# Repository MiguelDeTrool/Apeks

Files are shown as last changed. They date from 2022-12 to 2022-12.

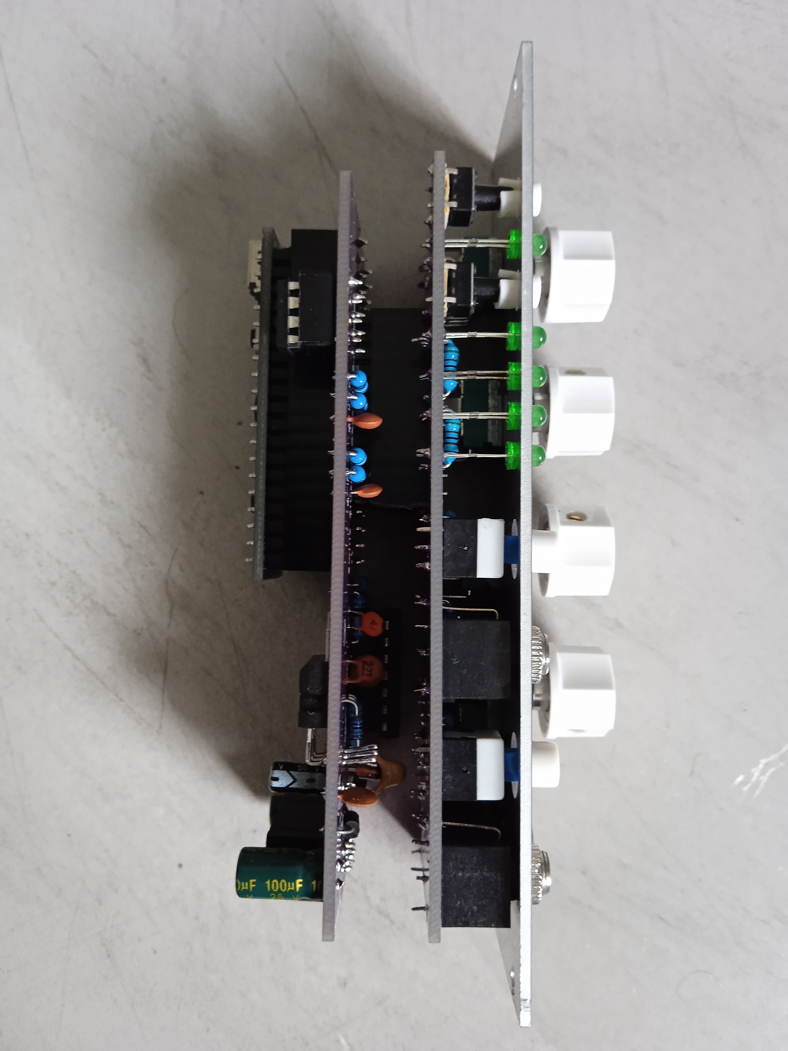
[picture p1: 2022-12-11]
img/4_left.jpg

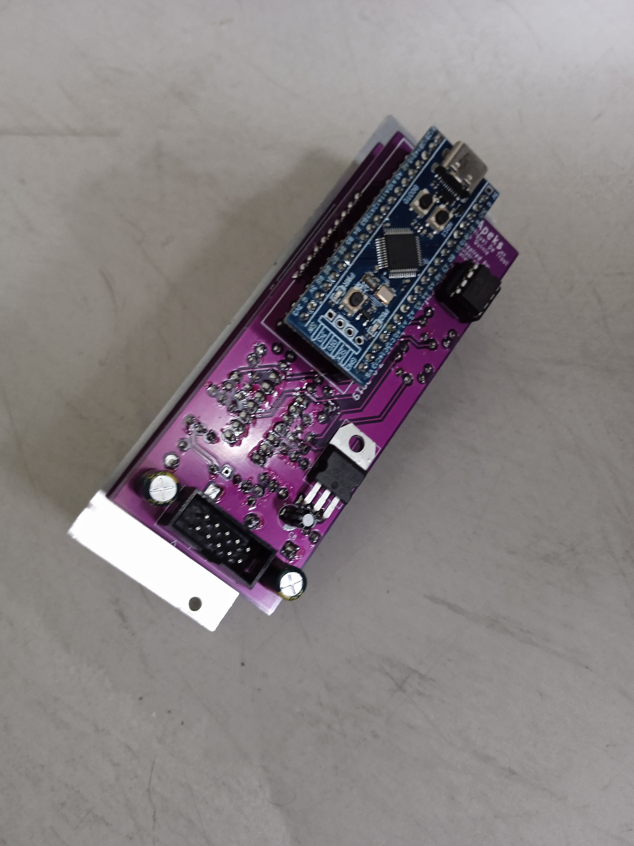
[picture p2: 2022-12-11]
img/3_back.jpg

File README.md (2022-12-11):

# Apeks

Apeks is a DIY 12-bit through-hole adaptation of Mutable Instruments Peaks. Peaks was discontinued in 2017, but it's still pretty useful, and you can still see it in modern racks. For a starter system, it offers lots of functionality, so we made a version that's cheap and easy to fabricate, build, and modify.



## Hardware:
We saw what sound-force.nl did for Braids, and noticed Peaks used the same classic STM32 processor, so the same style of conversion could be done. Overall the conversion process was very similar to what Sound Force describes in their page about Braids: the layout is the same as it leaves space for THT components, the main PCB is shorter than 100mm, and the firmware only needs to have a few files changed (dac.h, dac.cc, lfo.h, and mini_sequencer.h).

The output stage needed to be modified slightly, as Peaks' output swing is 16V, which at 12 bits means the resolution would only be at almost 4mV. That's almost 5 cents at 1V/Oct, which is too much, as we could hear the steps in the output.

This version uses a 12 bit DAC, and the output op-amps scale the output to +/- 5V. This allows for a resolution of around 2.44mV, which we find acceptable for non-pitch related modulation.

## Firmware
For the DAC, the dac.h file is modified to bitshift the 16 bit values by 4 bits. The SPI output message use masks according to the MCP4822 write commands.

To bring the LFOs and mini-sequencers up to the maximum level (if not, they would be at around +/-3.125V), a couple of changes are needed. The lfo.h set_level arguments need to be set to 65535 instead of 40960, and in the output line of mini_sequencer.h, the same number needs to be changed.

The firmware is available as source and pre-compiled. We used a CP2102 and STM32CubeProg to program the chip (see images for a wiring diagram).

When you use the module for the first time, flash the bootloader and the main firmware. Then take care to calibrate it according to [these instructions](https://forum.mutable-instruments.net/t/trimpots-versus-software-calibration-of-peaks/8213/2).

## Panel
There are two panel versions. One uses 6mm caps for the trigger buttons, with LEDs that shine through the PCB beside them. The other has 8mm holes for the original illuminated buttons.
*Note: We've only tried our prototype panels for now, we haven't had these panels fabricated yet.*

## Further modifications
This version stays as close as possible to the original, but we'd be excited to see further modifications and improvements. We're working on a 64kb firmware (no easter egg and smaller bootloader), and a Dead Man's Catch adaptation.

But why not try to add CV inputs with attenuverters for the pots, make an SMD micro version that can be pre-fabbed, use an adapter board to use another DAC, see if you can do the same for Tides v1 etc...

## Build notes
We've included a BOM with links to Tayda, where you can source almost all the parts quite cheaply. The BOM includes some helpful notes about some components.

It's very hard to get ahold of boards with genuine STM32 chips right now. We haven't tested this with any other versions, like APM32, GD32, CH32 etc... but we can only assume that they will work too. **Just be careful that the pinouts match!**

## Contact
This is a DIY project, with no instructions or build support. However, I can try to answer some questions you may have (if I have the time) at [migueldetrool@protonmail.com](mailto:migueldetrool@protonmail.com).

Check out [Quinie's blog and shop](https://www.quinie.nl), where there are PCB and panels for sale.

*If you get these boards or panels fabricated, please do contact me. These boards have been tested, but still, maybe I oversaw a problem, so it would be good to have confirmation that these work for others.*

### Thanks
Thanks to sound-force.nl and matias-levy for inspiration, and Emilie Gillet for the original design and helpful forum posts.

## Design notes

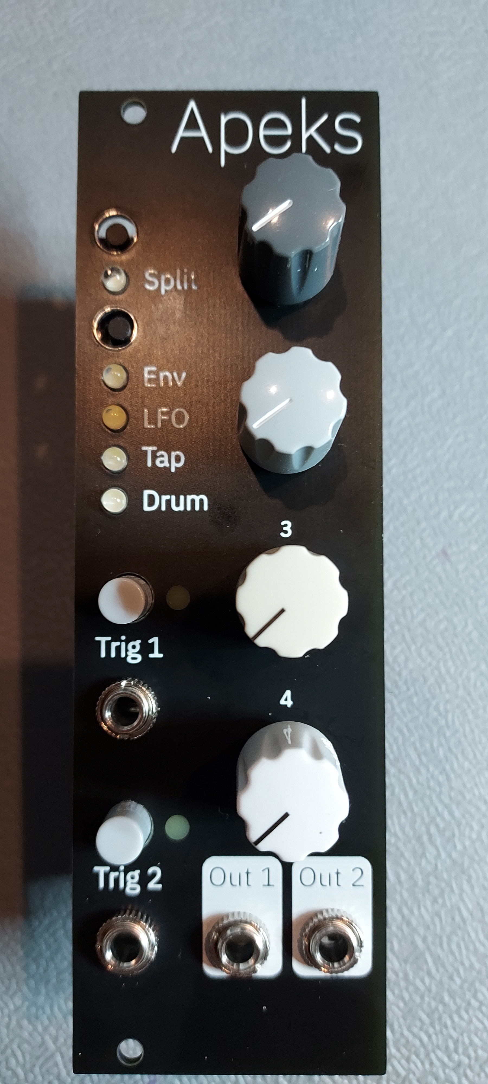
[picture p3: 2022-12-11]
img/7_front.jpg

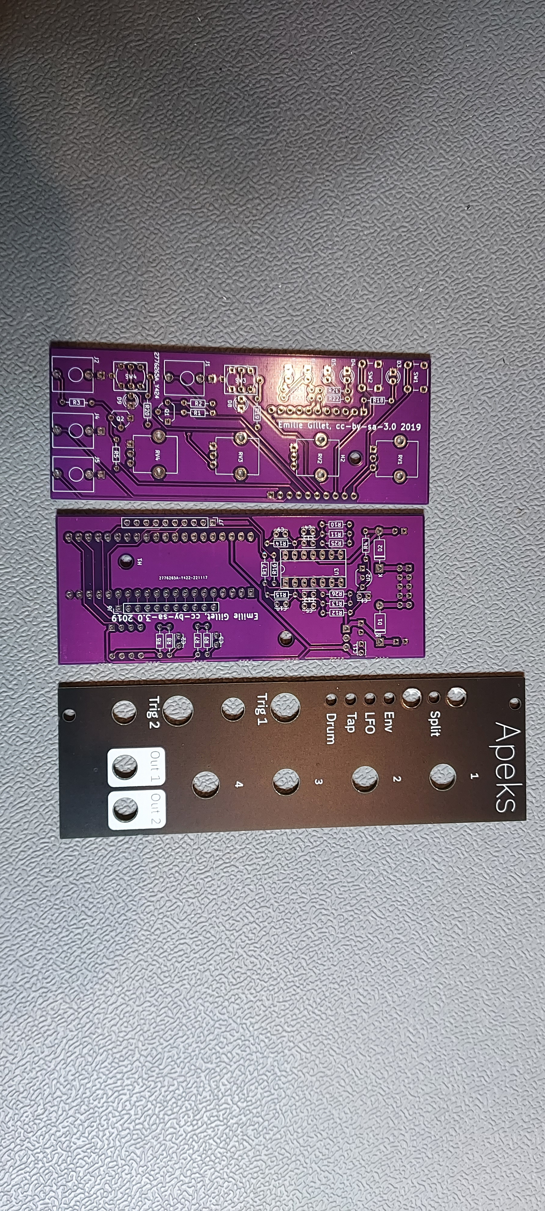
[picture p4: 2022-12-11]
img/6_three_PCBs.jpg

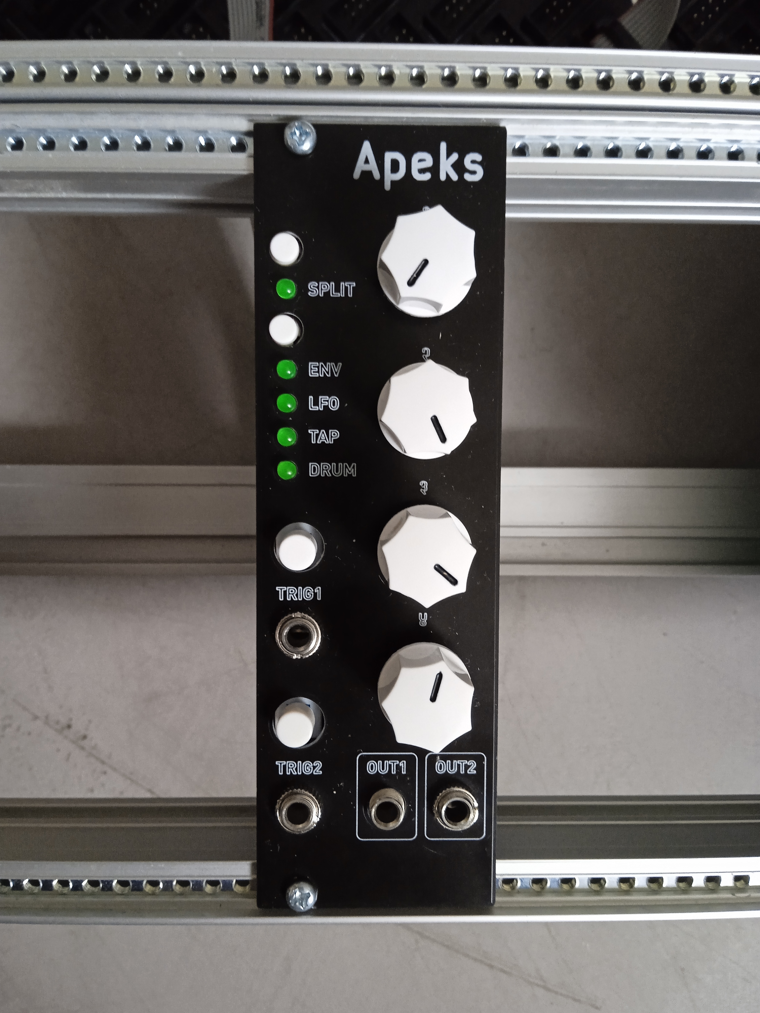
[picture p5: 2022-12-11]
img/1_front.jpg

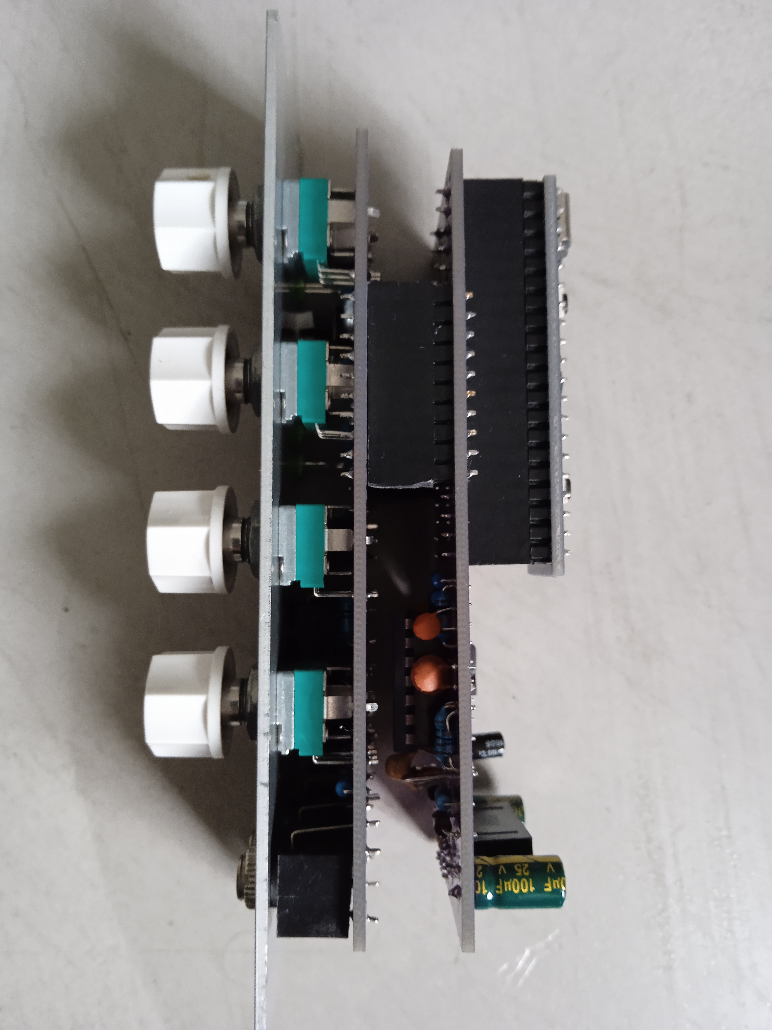
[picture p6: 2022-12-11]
img/5_right.jpg

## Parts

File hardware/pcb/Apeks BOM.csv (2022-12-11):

Designator | Description | Quantity | Designation | Link | Notes
C1 | C_Disc_D3.4mm_W2.1mm_P2.50mm | 1 | 0.47uf | https://www.taydaelectronics.com/capacitors/ceramic-disc-capacitors/test-group-2.html | Same link for all ceramic capacitors
C11,C12,C13 | C_Disc_D3.4mm_W2.1mm_P2.50mm | 3 | 100n
C4,C2,C3,C5 | C_Disc_D3.4mm_W2.1mm_P2.50mm | 4 | 220p
C6,C7 | CP_Radial_D5.0mm_P2.50mm | 2 | 22uf | https://www.taydaelectronics.com/22uf-25v-85c-radial-electrolytic-capacitor-5x11mm.html
C8 | CP_Radial_D5.0mm_P2.50mm | 1 | 0,33u | https://www.taydaelectronics.com/0-33-uf-50v-85c-radial-electrolytic-capacitor.html
C9,C10 | C_Disc_D3.4mm_W2.1mm_P2.50mm | 2 | 39p
D1,D2 | D_DO-41_SOD81_P10.16mm_Horizontal | 2 | 1N5817 | https://www.taydaelectronics.com/1n5817-diode-schottky-1a-20v.html | 1N5819 is actually cheaper
D3,D4,D5,D6,D7,D8,D9 | LED_D3.0mm | 7 | LED | https://www.taydaelectronics.com/led-3mm-green.html | Depending on what LEDs you get, they might be too bright and you’ll need bigger resistors for them
J1 | Jack_3.5mm_QingPu_WQP-PJ398SM_Vertical_CircularHoles | 1 | in1 | https://www.taydaelectronics.com/pj-3001f-3-5-mm-mono-phone-jack.html | Same link for all jacks
J2 | Jack_3.5mm_QingPu_WQP-PJ398SM_Vertical_CircularHoles | 1 | in2
J3 | IDC-Header_2x05_P2.54mm_Vertical | 1 | Eurorack Power | https://www.taydaelectronics.com/10-pin-box-header-connector-2-54mm.html
J4 | Jack_3.5mm_QingPu_WQP-PJ398SM_Vertical_CircularHoles | 1 | out1
J5 | Jack_3.5mm_QingPu_WQP-PJ398SM_Vertical_CircularHoles | 1 | out2
J6 | PinHeader_1x11_P2.54mm_Vertical | 1 | Conn_01x11 | https://www.taydaelectronics.com/40-pin-2-54-mm-single-row-pin-header-strip.html | Cut down to size
J7 | PinHeader_1x10_P2.54mm_Vertical | 1 | Conn_01x10 | https://www.taydaelectronics.com/40-pin-2-54-mm-single-row-female-pin-header.html | Cut down to size
J8 | PinSocket_1x11_P2.54mm_Vertical | 1 | Conn_01x11
J9 | PinSocket_1x10_P2.54mm_Vertical | 1 | Conn_01x10
Q1,Q2 | TO-92_Wide | 2 | 2N3904 | https://www.taydaelectronics.com/2n3904-npn-general-propose-transistor.html
R1,R3,R14,R15 | R_Axial_DIN0204_L3.6mm_D1.6mm_P7.62mm_Horizontal | 4 | 100k | https://www.taydaelectronics.com/resistors/1-4w-metal-film-resistors/test-group-2.html | Same link for all resistors
R10,R12 | R_Axial_DIN0204_L3.6mm_D1.6mm_P7.62mm_Horizontal | 2 | 200k
R11,R18,R21,R22,R23,R24,R19,R20,R13 | R_Axial_DIN0204_L3.6mm_D1.6mm_P7.62mm_Horizontal | 9 | 2k
R16,R17 | R_Axial_DIN0204_L3.6mm_D1.6mm_P7.62mm_Horizontal | 2 | 1k
R2,R5 | R_Axial_DIN0204_L3.6mm_D1.6mm_P7.62mm_Horizontal | 2 | 10k
R4 | R_Axial_DIN0204_L3.6mm_D1.6mm_P7.62mm_Horizontal | 1 | 3.3k
R6,R7,R8,R9,R25,R26 | R_Axial_DIN0204_L3.6mm_D1.6mm_P7.62mm_Horizontal | 6 | 39k
RV1,RV2,RV3,RV4 | Potentiometer_Alpha_RD901F-40-00D_Single_Vertical_CircularHoles | 4 | B10k | https://www.taydaelectronics.com/tayda-10k-ohm-linear-taper-potentiometer-round-shaft-pcb-9mm-6-35-mm.html
SW1,SW2 | SW_PUSH_6mm | 2 | SW_Push_Dual | https://www.aliexpress.com/item/32726374514.html | Ideally, you want 6*6mm tact switches with square heads, that will fit the cap nicely. If you want to only order from tayda, you can probably force the cap onto a round head switch, like this https://www.taydaelectronics.com/tact-switch-6-6mm-7-3mm-through-hole-spst-no.html
SW3 | LP4OA1PBCT | 1 | SW_TRIG1 | https://www.taydaelectronics.com/push-button-switch-momentary-dc-30v-0-1a-dpdt-7x7mm.html | For the original illuminated buttons with 8mm head, you can get these ones https://www.aliexpress.com/item/4000415375387.html?gatewayAdapt=4itemAdapt
SW4 | LP4OA1PBCT | 1 | SW_TRIG2 |  | Depending on which buttons you use, you may have to do some light re-wiring by adding jumpers between certain pins. On the board, the two middle pins need to connect to the two bottom pins when the button is pressed.
U1 | BluePill_STM32F103C | 1 | Bluepill |  | Needs STM32F103CBT6 version, with 128kb memory. You can only get clones of these currently. I’m working on a smaller version of firmware to work on 64kb.
U2 | TO-92_Inline_Wide | 1 | LM4040LP-10 |  | Not common on ali sites, since the output is not v/oct, it’s easiest to just replace it with a zener like this: https://www.taydaelectronics.com/1n4740a-1n4740-zener-diode-10v-1w.html
U3 | DIP-14_W7.62mm_Socket_LongPads | 1 | TL074 | https://www.taydaelectronics.com/tl074-quad-operational-amplifier-j-fet-pdip-14-tl074cn.html
U4 | DIP-8_W7.62mm | 1 | MCP4822 |  | Can be found on ali sites, like here: https://www.aliexpress.com/item/33020375029.html
U5 | TO-220-3_Horizontal_TabDown | 1 | LM7805 | https://www.taydaelectronics.com/lm7805-l7805-7805-voltage-regulator-ic-5v-1-5a.html
Extras
 | STM32 Blue Pill headers | 2 |  | https://www.taydaelectronics.com/20-pin-2-54-mm-single-row-female-pin-header.html | Some clone boards have a 5V pin at the top right, instead of the usual ground. Cut the pin off if it has 5V.
 | Tactile switch caps | 2 |  | https://www.taydaelectronics.com/push-button-switch-caps-black-color-5x8-85-mm.html
 | Push button caps, for 6mm version | 2 |  | https://www.taydaelectronics.com/push-button-switch-caps-black-color-6-x-5-mm.html
 | Potentiometer knobs | 4 |  | https://www.taydaelectronics.com/knob-davies-1900h-clone-black.html
 | 14 pin socket | 1 |  | https://www.taydaelectronics.com/14-pin-dip-ic-socket-adaptor-solder-type.html
 | 8 pin socket | 1 |  | https://www.taydaelectronics.com/8-pin-dip-ic-socket-adaptor-solder-type.html

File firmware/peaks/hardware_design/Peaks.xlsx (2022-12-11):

Peaks v3.1
Index | Qty | Description | Specs | Value | Package | Ref. Mouser | References
SMT parts
R10, R23 | 2 | Resistor, 1% |  | 33 | 0603 | 652-CR0603FX-33R0ELF
R2, R4, R6, R7, R8 | 5 | Resistor, 1% |  | 100 | 0603 | 652-CR0603FX-1000ELF
R20, R31 | 2 | Resistor, 1% |  | 1.0k | 0603 | 652-CR0603FX-1001ELF
R9, R25 | 2 | Resistor, 1% |  | 3.3k | 0603 | 652-CR0603-FX3301ELF
R3, R13, R16, R28 | 4 | Resistor, 1% |  | 10k | 0603 | 652-CR0603-FX-1002GLF
R12, R14, R17, R22, R24, R26 | 6 | Resistor, 1% |  | 39k | 0603 | 652-CR0603FX-3902ELF
R15, R27 | 2 | Resistor, 1% |  | 100k | 0603 | 652-CR0603-FX-1003GLF
R18, R29 | 2 | Resistor, 1% |  | 249k | 0603 | 652-CR0603FX-2493ELF
R19, R30 | 2 | Resistor, 1% |  | 309k | 0603 | 667-ERJ-3EKF3093V
C6, C7, C17, C23 | 4 | Capacitor, ceramic |  | 18p | 0603 | 81-GRM185C1H180JA01J
C14, C15, C19, C20 | 4 | Capacitor, ceramic | >= 16V, <= 2%, C0G | 220p | 0603 | 81-GRM185C1H221GA01D
C3, C5, C8, C9, C10, C12, C16, C18, C21, C24 | 10 | Capacitor, ceramic | >= 16V | 100n | 0603 | 81-GRM188R71E104JA1J
C11, C22 | 2 | Capacitor, ceramic | >= 16V | 470n | 0603 | 81-GRM18F51C474ZA01J
C13 | 1 | Capacitor, ceramic | >= 6.3V | 3.3u | 0603 | 81-GRM188R61A335KE5D
C1, C2, C4 | 3 | Capacitor, electrolytic | >= 25V | 22u | Panasonic C | 667-EEE-FP1E220AR | EEE-FP1E220AR
L1 | 1 | EMI Filter Bead | >= 2200 ohm |  | 0603 | 710-742792693 | Wurth Electronics 742792693
D1, D2 | 2 | 1N5819HW diode |  |  | SOD123 | 621-1N5819HW-F | Diodes Inc 1N5819HW-7-F
IC1 | 1 | LM1117-3.3V LDO Vreg |  | 3.3V | SO223 | 926-LM1117MPX3.3NOPB | National LM1117MPX3.3NOPB
IC2 | 1 | LM4040 Shunt Vref | A, B or C grade | 2.5V | SOT23 | 595-LM4040C25IDBZR | Texas Instruments LM4040C25IDBZ
IC6 | 1 | LM4040 Shunt Vref | A, B or C grade | 10V | SOT23 | 595-LM4040C10IDBZR | Texas Instruments LM4040C10IDBZ
IC3 | 1 | DAC8552 dual 16-bit DAC |  |  | MSOP8 | 595-DAC8552IDGKT | Texas Instruments DAC8552IDGKT
IC4, IC5 | 2 | OPA2171 dual op-amp |  |  | SOIC8 | 595-OPA2171AID | TI OPA2171AID
Q2, Q3 | 2 | NPN transistor MMBT3904 |  |  | SOT23 | 863-MMBT3904LT1G | On Semi MMBT3904LT1G
Q1 | 1 | 8 MHz quartz |  |  | HC49 | 815-ABLS2-8-D4Y-T | Abracon ABLS2-8.000MHZ-D4Y-T
SW3, SW5 | 2 | Switch, 6mm, SMT |  |  | 6mm x 6mm | 667-EVQ-Q2K01W | Panasonic EVQ-Q2K01W
UC1 | 1 | STM32F103CBT6 MCU |  |  | LQFP48 | 511-STM32F103CBT6 | ST STM32F103CBT6
PTH parts, top side |  | MFG Part No:D6R90 F1 LFS
J1, J2, J3, J4 | 4 | Vertical jack connector |  |  |  |  | PJ-301-M-12
LED1, LED2, LED3, LED4, LED5 | 5 | LED 3mm, green, round |  |  |  | 604-WP710A10GD | Kingbright WP710A10GD ou L-710A10GD
- LED1, LED2, LED3, LED4, LED5 | 5 | LED holder | 10mm |  |  |  | LED3-10 Multicomp; Farnell P/N 9555277
R1, R5, R11, R21 | 4 | 10k linear pot, 15mm shaft |  |  |  |  | https://www.thonk.co.uk/shop/alpha-9mm-pots/
SW4, SW6 | 2 | Switch, On-mom, Green LED |  |  |  |  | E-switch LP4OA1PBCTG
SW1, SW2 | 2 | Switch, 6mm |  |  |  | 612-TL1105SP-250 | E-switch TL1105SPF250Q
 | 2 | Cap for switch, black |  |  |  | 612-1R-BK | E-switch 1RBLK
PTH parts, bottom side
JP3 | 1 | 2x5 male header, 2.54mm pitch |  |  |  | 649-67996-410HLF
JP2 | 1 | 2x5, 1.27mm pitch male header |  |  |  | 649-221111-00010T4LF
JP1 | 1 | 1x6 male header, 2.54mm pitch |  |  |  | 649-68002-106HLF
PCB specifications
PCB |  | 38.7 x 106.7 ; 2 layers

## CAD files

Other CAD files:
firmware/peaks/hardware_design/panel/peaks.dwg

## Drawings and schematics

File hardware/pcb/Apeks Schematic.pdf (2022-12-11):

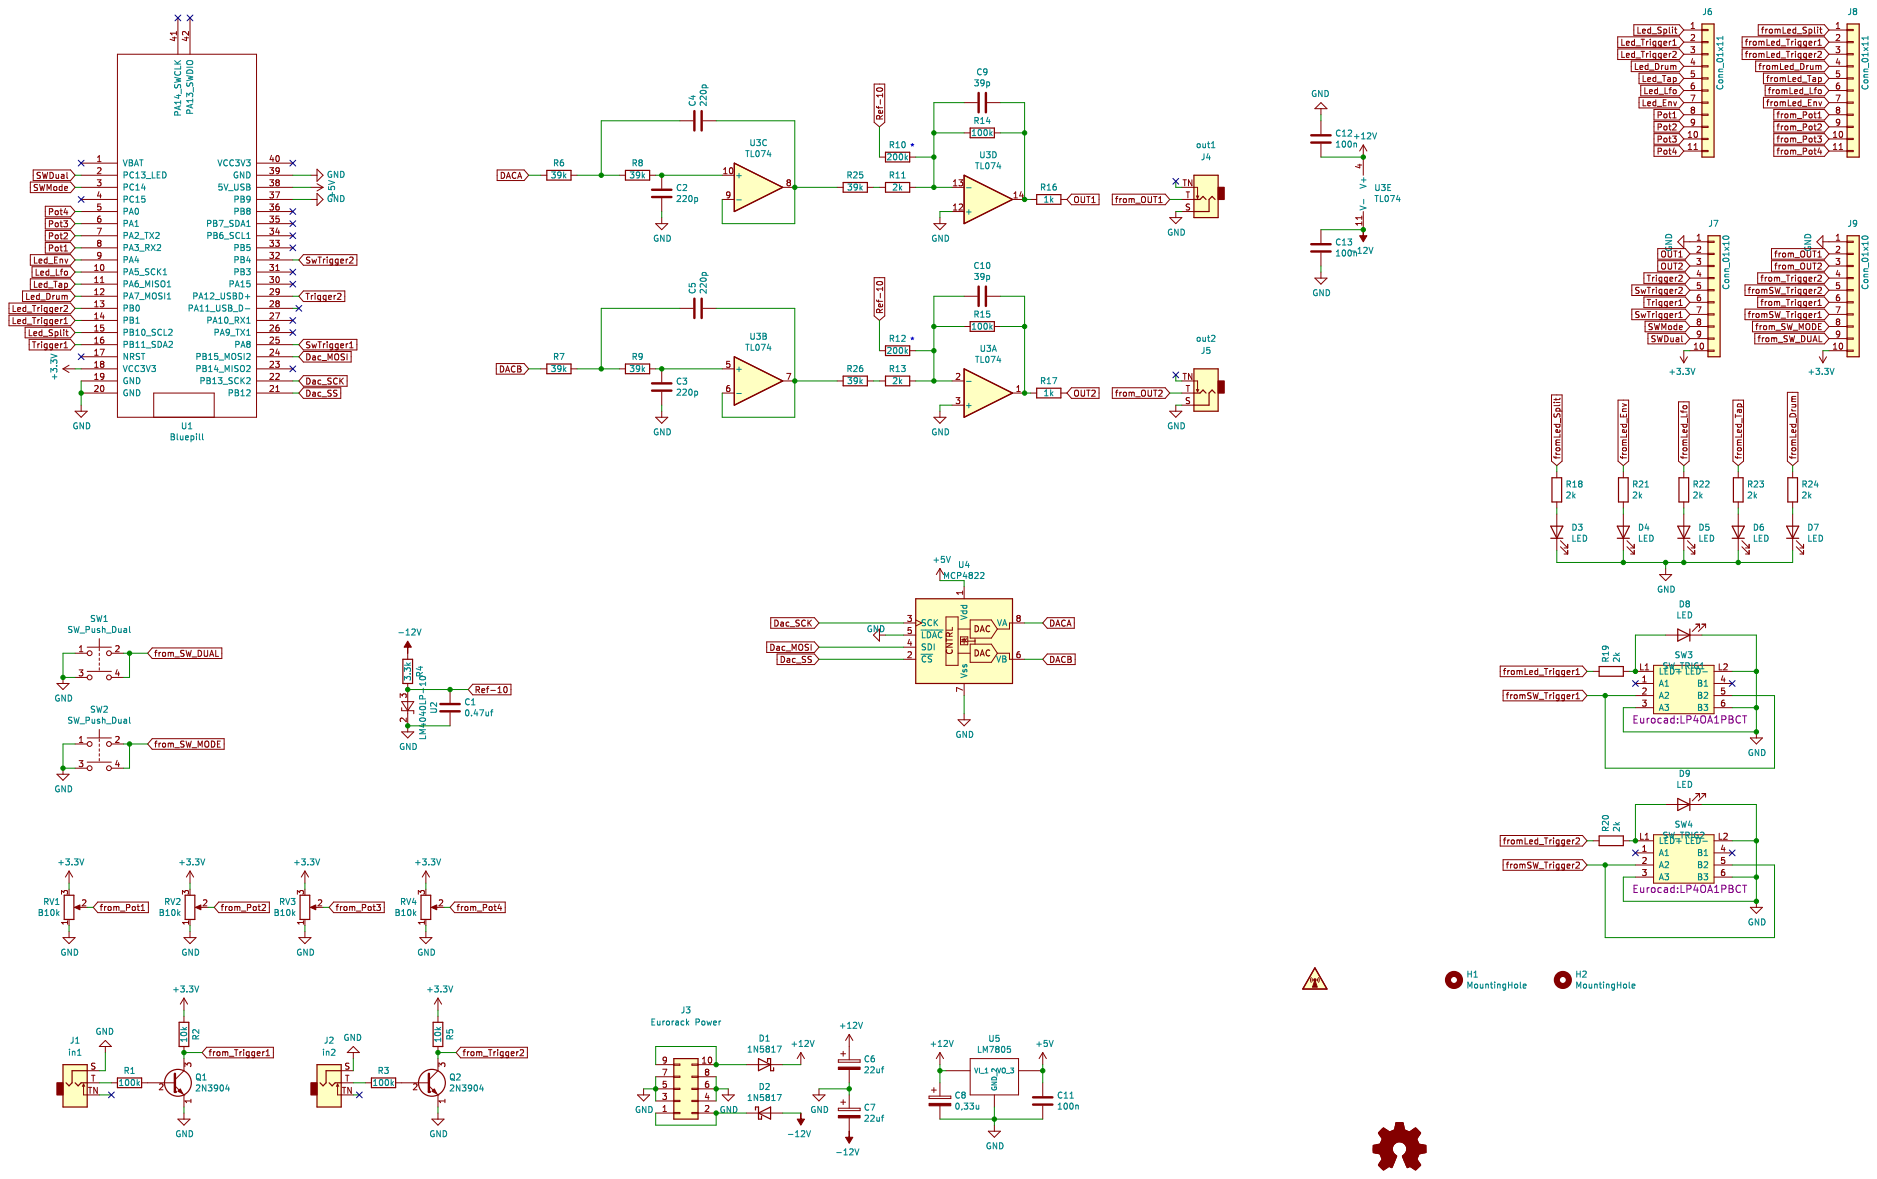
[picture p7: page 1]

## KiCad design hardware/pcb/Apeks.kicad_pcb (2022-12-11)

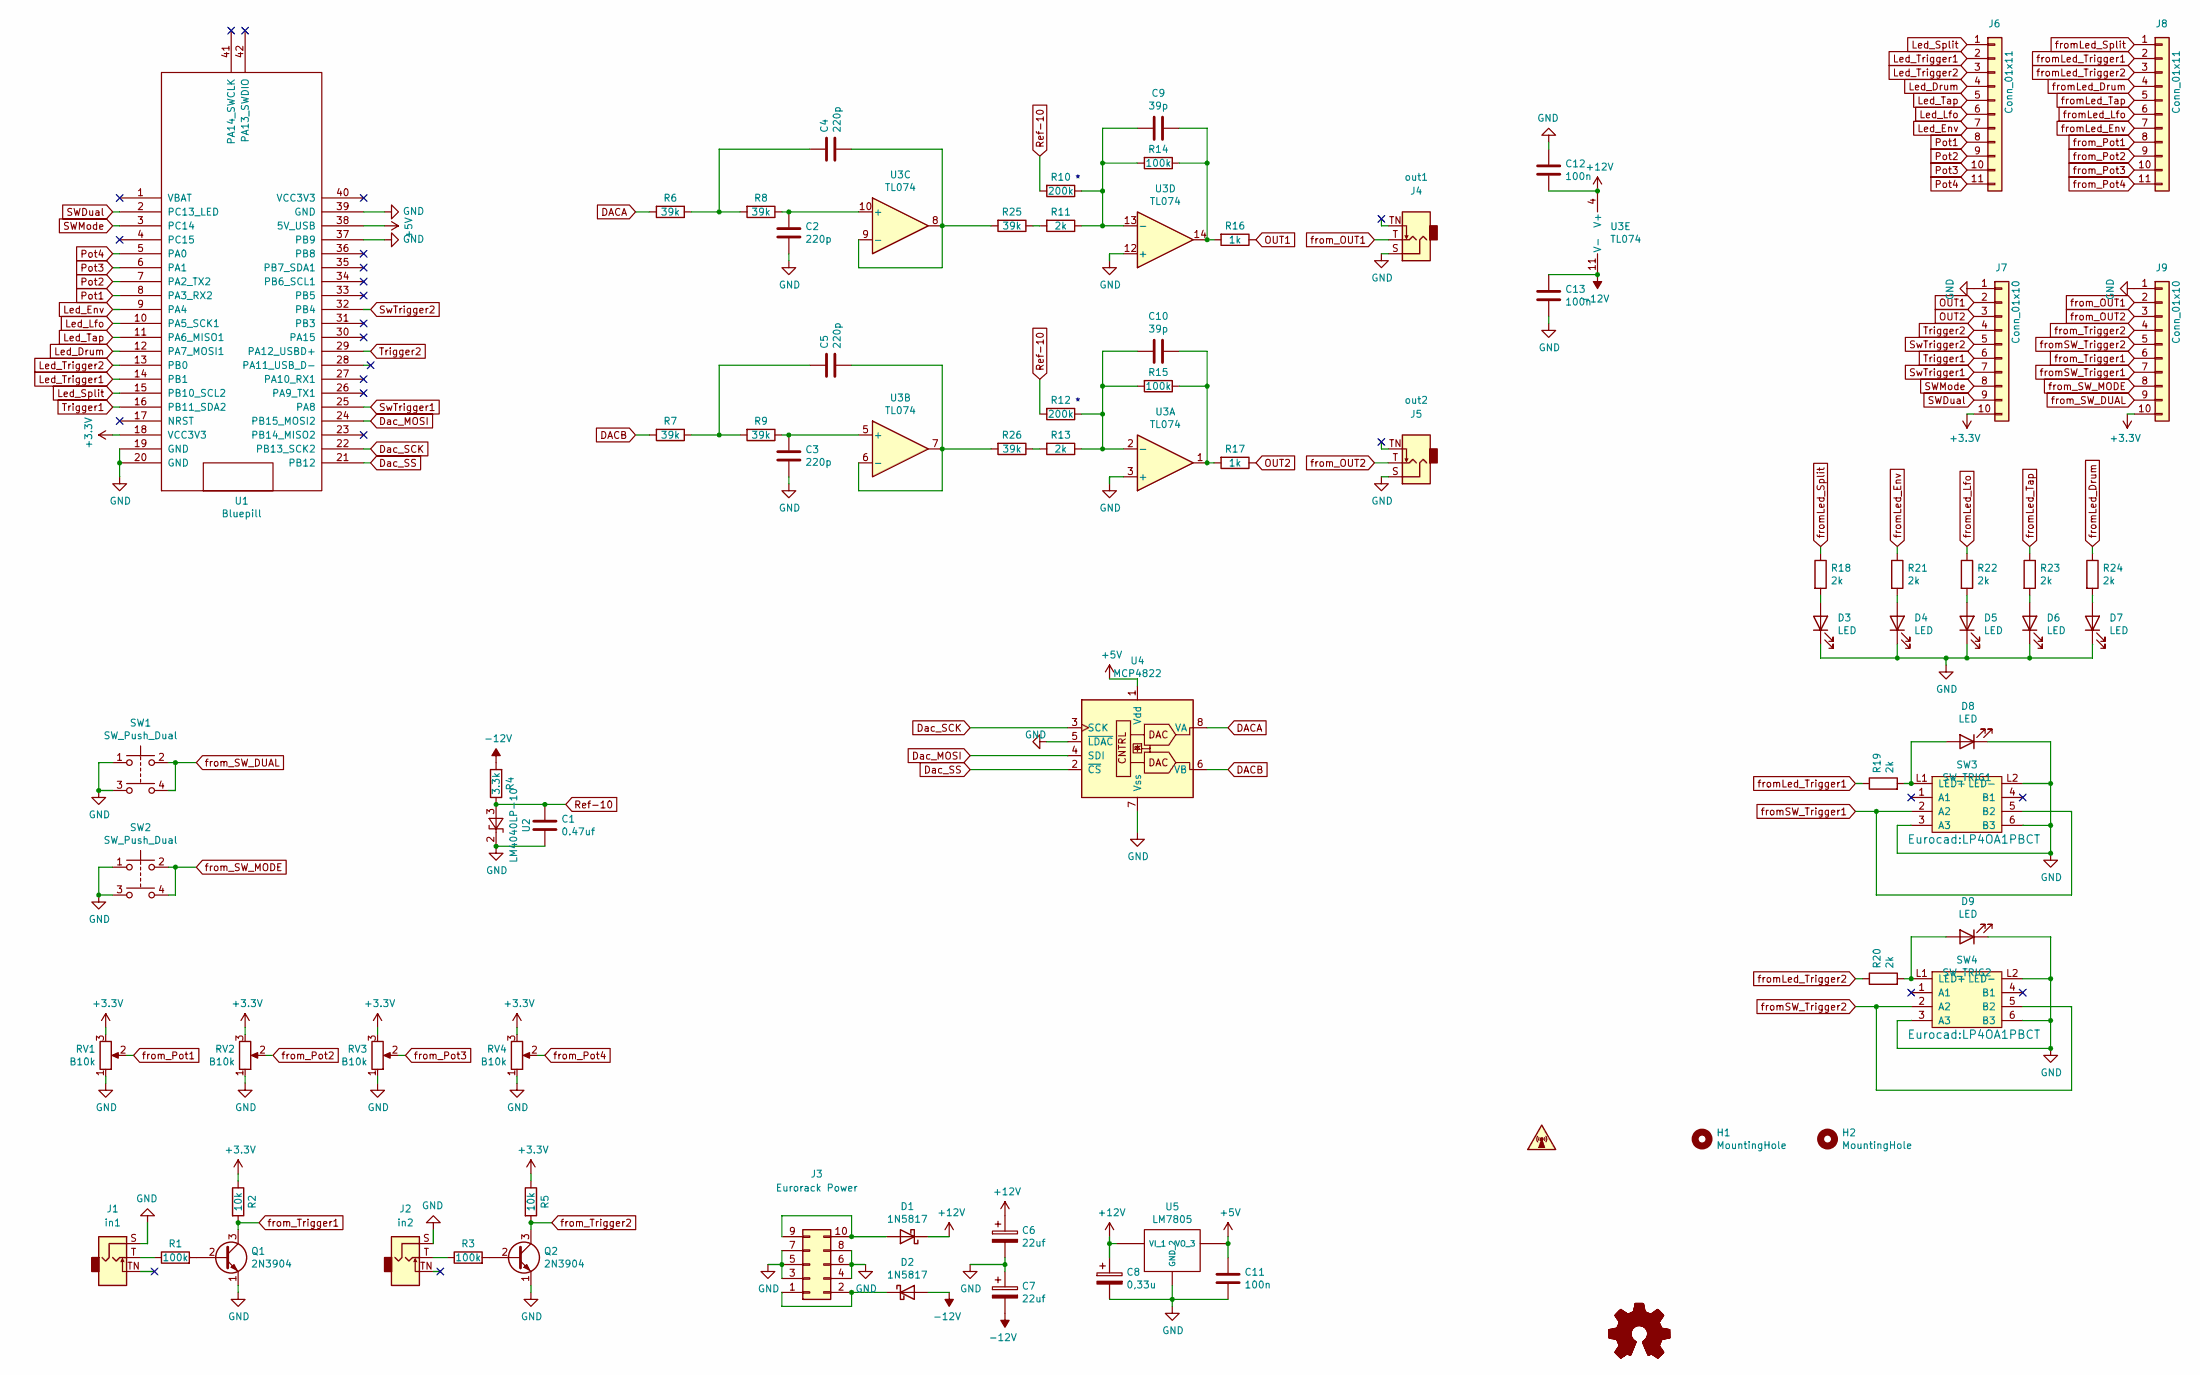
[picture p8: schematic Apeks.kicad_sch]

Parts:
C1: 0.47uf; C_Disc_D3.4mm_W2.1mm_P2.50mm
C2, C3, C4, C5: 220p; C_Disc_D3.4mm_W2.1mm_P2.50mm
C6, C7: 22uf; CP_Radial_D5.0mm_P2.50mm
C8: 0,33u; CP_Radial_D5.0mm_P2.50mm
C9, C10: 39p; C_Disc_D3.4mm_W2.1mm_P2.50mm
C11, C12, C13: 100n; C_Disc_D3.4mm_W2.1mm_P2.50mm
D1, D2: 1N5817; D_DO-41_SOD81_P10.16mm_Horizontal
D3, D4, D5, D6, D7, D8, D9: LED; LED_D3.0mm
H1, H2: MountingHole; MountingHole_3.2mm_M3
J1: in1; Jack_3.5mm_QingPu_WQP-PJ398SM_Vertical_CircularHoles
J2: in2; Jack_3.5mm_QingPu_WQP-PJ398SM_Vertical_CircularHoles
J3: Eurorack Power; IDC-Header_2x05_P2.54mm_Vertical
J4: out1; Jack_3.5mm_QingPu_WQP-PJ398SM_Vertical_CircularHoles
J5: out2; Jack_3.5mm_QingPu_WQP-PJ398SM_Vertical_CircularHoles
J6: Conn_01x11; PinHeader_1x14_P2.54mm_Vertical
J7: Conn_01x10; PinHeader_1x07_P2.54mm_Vertical
J8: Conn_01x11; PinSocket_1x14_P2.54mm_Vertical
J9: Conn_01x10; PinSocket_1x07_P2.54mm_Vertical
Q1, Q2: 2N3904; TO-92_Inline
R1, R3, R14, R15: 100k; R_Axial_DIN0204_L3.6mm_D1.6mm_P7.62mm_Horizontal
R2, R5: 10k; R_Axial_DIN0204_L3.6mm_D1.6mm_P7.62mm_Horizontal
R4: 3.3k; R_Axial_DIN0204_L3.6mm_D1.6mm_P7.62mm_Horizontal
R6, R7, R8, R9, R25, R26: 39k; R_Axial_DIN0204_L3.6mm_D1.6mm_P7.62mm_Horizontal
R10, R12: 200k; R_Axial_DIN0204_L3.6mm_D1.6mm_P7.62mm_Horizontal
R11, R13, R18, R19, R20, R21, R22, R23, R24: 2k; R_Axial_DIN0204_L3.6mm_D1.6mm_P7.62mm_Horizontal
R16, R17: 1k; R_Axial_DIN0204_L3.6mm_D1.6mm_P7.62mm_Horizontal
RV1, RV2, RV3, RV4: B10k; Potentiometer_Alps_RK09K_Single_Vertical
SW1, SW2: SW_Push_Dual; SW_PUSH_6mm
SW3: SW_TRIG1; LP4OA1PBCT
SW4: SW_TRIG2; LP4OA1PBCT
U1: Bluepill; BluePill_STM32F103C
U2: LM4040LP-10; TO-92_Inline
U3: TL074; DIP-14_W7.62mm_Socket_LongPads
U4: MCP4822; DIP-8_W7.62mm
U5: LM7805; TO-220-3_Horizontal_TabDown

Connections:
+3V3: J7.10, J9.10, R2.1, R5.1, RV1.3, RV2.3, RV3.3, RV4.3, U1.18 (VCC3V3)
+5V: C11.1, U1.38 (5V_USB), U4.1 (Vdd), U5.3 (VO)
+12V: C6.1, C8.1, C12.2, D1.1 (K), U3.4 (V+), U5.1 (VI)
-12V: C7.2, C13.1, D2.2 (A), R4.2, U3.11 (V-)
DACA: R6.2, U4.8 (VA)
DACB: R7.2, U4.6 (VB)
Dac_MOSI: U1.24 (PB15_MOSI2), U4.4 (SDI)
Dac_SCK: U1.22 (PB13_SCK2), U4.3 (SCK)
Dac_SS: U1.21 (PB12), U4.2 (~CS)
GND: C1.2, C2.2, C3.2, C6.2, C7.1, C8.2, C11.2, C12.1, C13.2, D3.1 (K), D4.1 (K), D5.1 (K), D6.1 (K), D7.1 (K), D8.1 (K), D9.1 (K), J1.S, J2.S, J3.3, J3.4, J3.5, J3.6, J3.7, J3.8, J4.S, J5.S, J7.1, J9.1, Q1.1 (E), Q2.1 (E), RV1.1, RV2.1, RV3.1, RV4.1, SW1.1, SW1.3, SW2.1, SW2.3, SW3.3 (A3), SW3.6 (B3), SW3.L2 (LED-), SW4.3 (A3), SW4.6 (B3), SW4.L2 (LED-), U1.19 (GND), U1.20 (GND), U1.37 (PB9), U1.39 (GND), U2.2 (K), U3.3 (+), U3.12 (+), U4.5 (~LDAC), U4.7 (Vss), U5.2 (GND)
Led_Drum: J6.4, U1.12 (PA7_MOSI1)
Led_Env: J6.7, U1.9 (PA4)
Led_Lfo: J6.6, U1.10 (PA5_SCK1)
Led_Split: J6.1, U1.15 (PB10_SCL2)
Led_Tap: J6.5, U1.11 (PA6_MISO1)
Led_Trigger1: J6.2, U1.14 (PB1)
Led_Trigger2: J6.3, U1.13 (PB0)
unnamed: C2.1, R8.1, U3.10 (+)
unnamed: C3.1, R9.1, U3.5 (+)
unnamed: C4.1, R6.1, R8.2
unnamed: C4.2, R25.2, U3.8, U3.9 (-)
unnamed: C5.1, R7.1, R9.2
unnamed: C5.2, R26.2, U3.6 (-), U3.7
unnamed: C9.1, R10.1, R11.1, R14.2, U3.13 (-)
unnamed: C9.2, R14.1, R16.2, U3.14
unnamed: C10.1, R12.1, R13.1, R15.2, U3.2 (-)
unnamed: C10.2, R15.1, R17.2, U3.1
unnamed: D1.2 (A), J3.9, J3.10
unnamed: D2.1 (K), J3.1, J3.2
unnamed: D3.2 (A), R18.2
unnamed: D4.2 (A), R21.2
unnamed: D5.2 (A), R22.2
unnamed: D6.2 (A), R23.2
unnamed: D7.2 (A), R24.2
unnamed: D8.2 (A), R19.2, SW3.L1 (LED+)
unnamed: D9.2 (A), R20.2, SW4.L1 (LED+)
unnamed: J1.T, R1.1
unnamed: J2.T, R3.1
unnamed: Q1.2 (B), R1.2
unnamed: Q2.2 (B), R3.2
unnamed: R11.2, R25.1
unnamed: R13.2, R26.1
OUT1: J7.2, R16.1
OUT2: J7.3, R17.1
Pot1: J6.8, U1.8 (PA3_RX2)
Pot2: J6.9, U1.7 (PA2_TX2)
Pot3: J6.10, U1.6 (PA1)
Pot4: J6.11, U1.5 (PA0)
Ref-10: C1.1, R4.1, R10.2, R12.2, U2.3 (A)
SWDual: J7.9, U1.2 (PC13_LED)
SWMode: J7.8, U1.3 (PC14)
SwTrigger1: J7.7, U1.25 (PA8)
SwTrigger2: J7.5, U1.32 (PB4)
Trigger1: J7.6, U1.16 (PB11_SDA2)
Trigger2: J7.4, U1.29 (PA12_USBD+)
fromLed_Drum: J8.4, R24.1
fromLed_Env: J8.7, R21.1
fromLed_Lfo: J8.6, R22.1
fromLed_Split: J8.1, R18.1
fromLed_Tap: J8.5, R23.1
fromLed_Trigger1: J8.2, R19.1
fromLed_Trigger2: J8.3, R20.1
fromSW_Trigger1: J9.7, SW3.2 (A2), SW3.5 (B2)
fromSW_Trigger2: J9.5, SW4.2 (A2), SW4.5 (B2)
from_OUT1: J4.T, J9.2
from_OUT2: J5.T, J9.3
from_Pot1: J8.8, RV1.2
from_Pot2: J8.9, RV2.2
from_Pot3: J8.10, RV3.2
from_Pot4: J8.11, RV4.2
from_SW_DUAL: J9.9, SW1.2, SW1.4
from_SW_MODE: J9.8, SW2.2, SW2.4
from_Trigger1: J9.6, Q1.3 (C), R2.2
from_Trigger2: J9.4, Q2.3 (C), R5.2

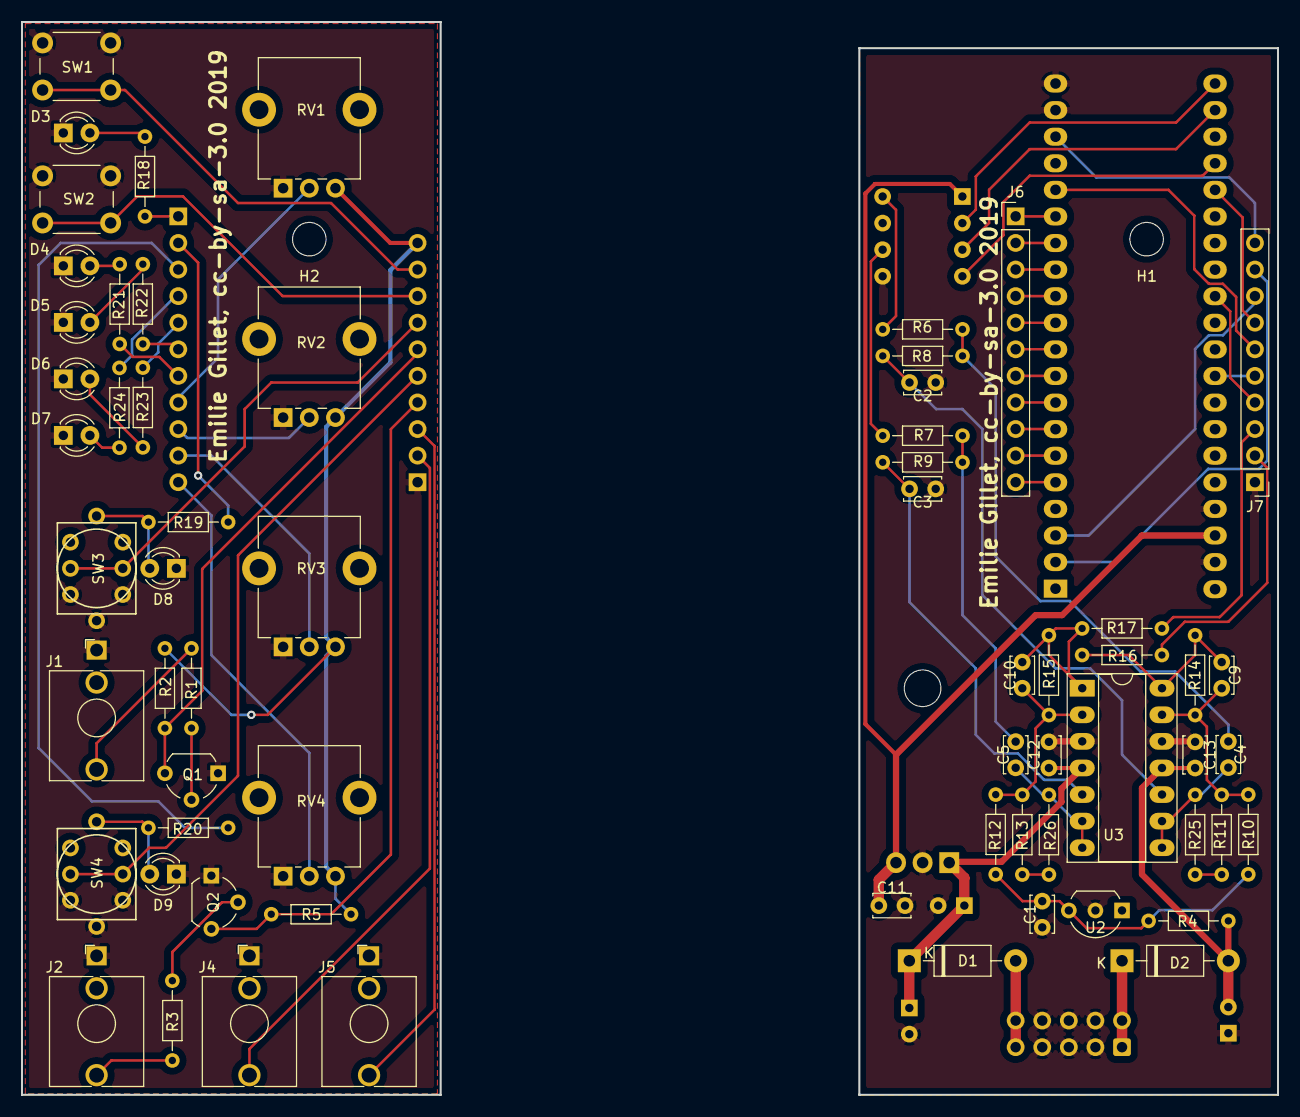
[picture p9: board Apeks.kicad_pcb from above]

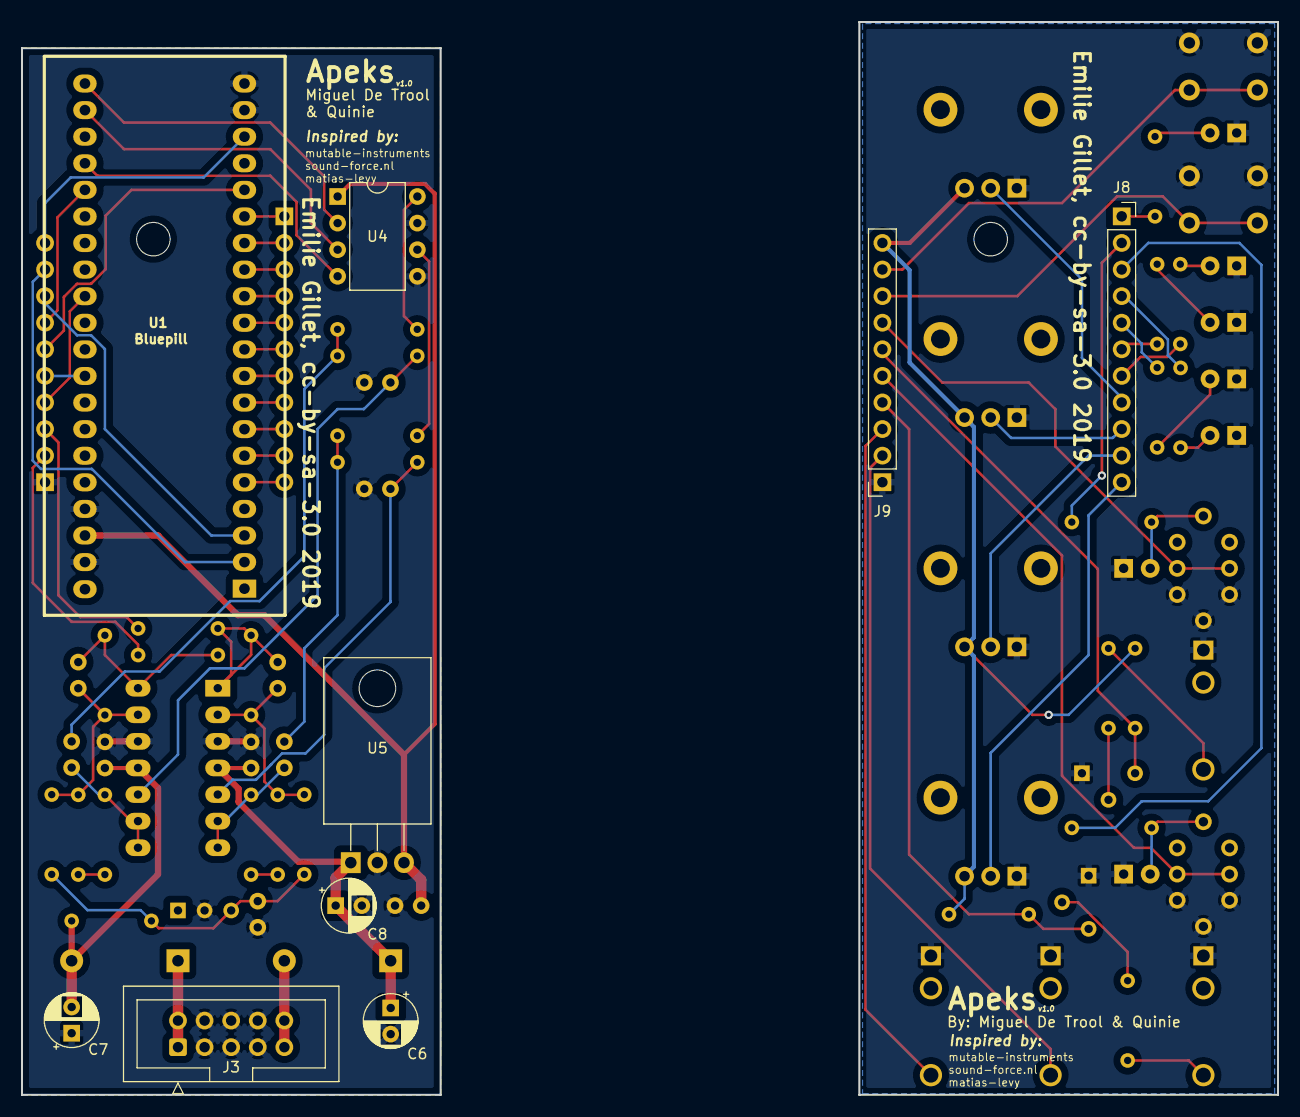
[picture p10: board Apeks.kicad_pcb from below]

Board: 2 copper layers, 120.0 x 102.5 mm, 74 parts (9 on the bottom side), 74 nets.

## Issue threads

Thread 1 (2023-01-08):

Question about firmwares

Testbild-synth, 2023-01-08:
Hey, great work!
Im building your module right now and I'm getting kind of lost with the firmware upload, especially because I've never worked with blue pills before and they seem to be a bit peculiar with uploading things (boot jumpers, bootloader and programm flashing etc).

So I'm kind of confused as to what the different firmwares are that you have compiled, could you maybe add a bit of documentation to what they are and the upload process in general?
For my bluepill board, the only combination of firmwares that I managed to upload correctly is the 8002000 bootloader with the no_eastereggs firmware. Not sure what the differences here is.

MiguelDeTrool, 2023-01-08:
Hello, you are probably using a 64kB bluepill (part number STM32F103C8T6), and not the original 128kB (CBT6). The 0x08002000_NoEasterEgg.hex version makes the firmware as small as possible by removing the easter egg, to allow the use of 64kB parts. It is still untested.

As for documentation about uploading, you can find many tutorials concerning how to uploaded precompiled firmware to STM32 boards. The easiest method is probably to use an STLink with the STM32CubeProgrammer, which Kristian Blasol explains well in his [video here](https://youtu.be/q5mbdBCou-k?t=4879).

MiguelDeTrool, 2023-01-08:
Hello, you are probably using a 64kB bluepill (part number STM32F103C8T6), and not the original 128kB (CBT6). The 0x08002000_NoEasterEgg.hex version makes the firmware as small as possible by removing the easter egg, to allow the use of 64kB parts. It is still untested.

As for documentation about uploading, you can find many tutorials concerning how to uploaded precompiled firmware to STM32 boards. The easiest method is probably to use an STLink with the STM32CubeProgrammer, which Kristian Blasol explains well in his [video here](https://youtu.be/q5mbdBCou-k?t=4879).

Testbild-synth, 2023-01-09:
@MiguelDeTrool thanks for notifying. Yes I have a 64k bluepill, and the 08002000 NoEasterEgg works with it :+1:
The thing is now that for me, the output 1 and 2 are switched. (trig switches and lights are fine, just the output jacks).
Simple to fix by cutting the trace and soldering two cables, but idk if that is specific to the 08002000 version or a general issue you might wanna look into. Either way my unit is fully working now, thanks again for the great work!

MiguelDeTrool, 2023-01-09:
The 0x08002000 version was developed on a prototype, hence why it is untested. The DAC codes need to be switched in the firmware and recompiled. But you can indeed also just switch it in hardware by cutting some traces and adding jumpers.

MiguelDeTrool, 2023-02-09:
I'm still doing some testing with a 64kB board, and having some struggles. I've added a minified firmware with switched channels, you can try both, and see if one works.

Closed 2023-01-08.

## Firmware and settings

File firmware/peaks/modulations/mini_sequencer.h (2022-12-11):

// Copyright 2013 Emilie Gillet.
//
// Author: Emilie Gillet (emilie.o.gillet@gmail.com)
//
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
// See http://creativecommons.org/licenses/MIT/ for more information.
//
// -----------------------------------------------------------------------------
//
// Mini sequencer.

#ifndef PEAKS_MODULATIONS_MINI_SEQUENCER_H_
#define PEAKS_MODULATIONS_MINI_SEQUENCER_H_

#include "stmlib/stmlib.h"

#include <algorithm>

#include "peaks/gate_processor.h"

namespace peaks {

const uint8_t kMaxNumSteps = 4;

class MiniSequencer {
 public:
  MiniSequencer() { }
  ~MiniSequencer() { }
  
  void Init() {
    std::fill(&steps_[0], &steps_[kMaxNumSteps], 0);
    num_steps_ = 4;
    step_ = 0;
    reset_at_next_clock_ = false;
  }
  
  inline void set_step(uint8_t index, int16_t value) {
    int32_t difference = abs(int32_t(steps_[index]) - value);
    if (difference > 0) {
      steps_[index] = value;
    }
  }
  
  inline void set_num_steps(uint8_t num_steps) {
    num_steps_ = num_steps;
  }
  
  void Configure(uint16_t* parameter, ControlMode control_mode) {
    if (control_mode == CONTROL_MODE_HALF) {
      set_step(0, parameter[0] - 32768);
      set_step(1, parameter[1] - 32768);
      set_num_steps(2);
    } else {
      set_step(0, parameter[0] - 32768);
      set_step(1, parameter[1] - 32768);
      set_step(2, parameter[2] - 32768);
      set_step(3, parameter[3] - 32768);
      set_num_steps(4);
    }
  }
  
  void Process(const GateFlags* gate_flags, int16_t* out, size_t size) {
    while (size--) {
      GateFlags gate_flag = *gate_flags++;
      if (gate_flag & GATE_FLAG_RISING) {
        ++step_;
        if (reset_at_next_clock_) {
          reset_at_next_clock_  = false;
          step_ = 0;
        }
      }
      if (num_steps_ > 2 && gate_flag & GATE_FLAG_AUXILIARY_RISING) {
        reset_at_next_clock_ = true;
      }
      if (step_ >= num_steps_) {
        step_ = 0;
      }
      *out++ = static_cast<int32_t>(steps_[step_]) * 65535 >> 16;
    }
  }
  
 private:
  uint8_t num_steps_;
  uint8_t step_;
  int16_t steps_[kMaxNumSteps];

  bool reset_at_next_clock_;

  DISALLOW_COPY_AND_ASSIGN(MiniSequencer);
};

}  // namespace peaks

#endif  // PEAKS_MODULATIONS_MINI_SEQUENCER_H_

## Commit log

2022-12-11 Add firmware source code
    [Peaks.xlsx, peaks.dwg, peaks_v30.brd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]
2023-02-09 Add switched channels minified firmware
2023-02-09 Switch channel files

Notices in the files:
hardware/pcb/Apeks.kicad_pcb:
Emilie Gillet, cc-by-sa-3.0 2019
